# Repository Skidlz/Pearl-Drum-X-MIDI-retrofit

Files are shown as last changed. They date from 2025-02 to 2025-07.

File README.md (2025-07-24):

# Pearl Drum-X MIDI retrofit
 A MIDI retrofit board for Pearl's Drum-X (DRX-1) drum synthesizer

The project is designed around an Atmega*8 that controls a MAX528 octal DAC.

### Install Guide
[Here](https://docs.google.com/document/d/1SWIhVnxzadJWSYvPP88jSyq_Yxp76ufy1qYrGyIhOZM/edit?usp=sharing) is a quick explanation of the connections that need to be made to install the board.

### DAC
Five DAC outputs are used to generate triggers with different voltages based on MIDI velocity.

One output is used to generate eight control voltages for each of the five voices. Timing signals are received from the Pearl's motherboard, and are used to syncronize the stream of multiplexed CV signals.

### Use
The boards starts up in "MIDI learn" mode, and loads default settings for each voice. The board will assign itself to the first channel it receives a message on. The notes that it responds to, and the voice defaults are hard-coded in the firmware.

The voice paramaters are mapped to the first 40 MIDI CCs in this order: Pitch, Bend, Osc/Noise Mix, Over Tone, Attack, Filter, Decay, Level

### Atmega328p
The fuse bits of the Atmega328p need to be set for an external 16MHz crystal oscillator. The chips default to using the internal osc, and the firmware does not support this.
The following values can be programmed with avrdude: L:0xFF, H:0xD9, E:0xFF 

### Schematic
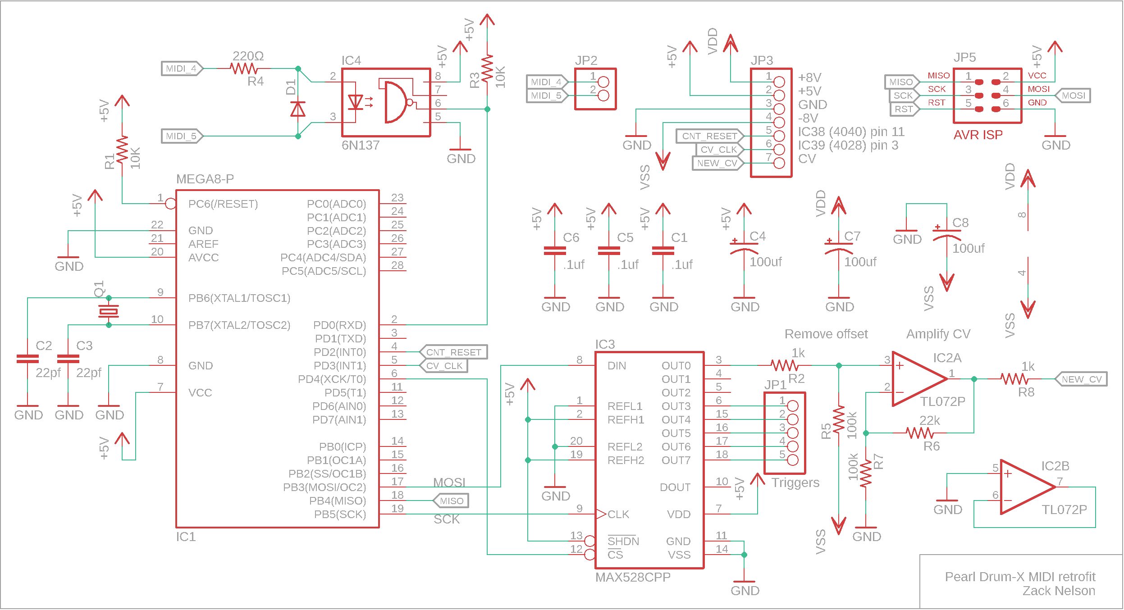
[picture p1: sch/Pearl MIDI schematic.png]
Schematic


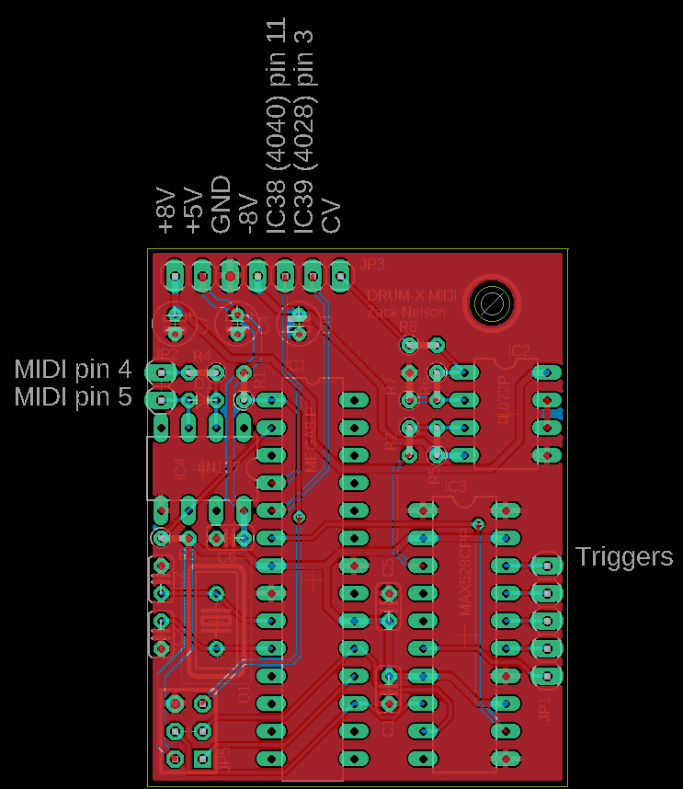
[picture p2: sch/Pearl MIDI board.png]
Board


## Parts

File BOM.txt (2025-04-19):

Qty Value         Device          Package      Parts      Description                          MF MPN       OC_FARNELL OC_NEWARK
1                 PINHD-1X2       1X02         JP2        PIN HEADER                                                            
1                 PINHD-1X5       1X05         JP1        PIN HEADER                                                            
1                 PINHD-1X7       1X07         JP3        PIN HEADER                                                            
3   .1uf          C-EU025-024X044 C025-024X044 C1, C5, C6 CAPACITOR, European symbol                                            
2   100k          R-US_0204/2V    0204V        R5, R7     RESISTOR, American symbol                                             
3   100uf         CPOL-USE1.8-4   E1,8-4       C4, C7, C8 POLARIZED CAPACITOR, American symbol                                  
2   10K           R-US_0204/2V    0204V        R1, R3     RESISTOR, American symbol                                             
1   16MHz         CRYSTALHC18U-V  HC18U-V      Q1         CRYSTAL                                           unknown    unknown  
1   1N4148        DIODE-D-2.5     D-2.5        D1         DIODE                                                                 
2   1k            R-US_0204/2V    0204V        R2, R8     RESISTOR, American symbol                                             
1   220Ω          R-US_0204/2V    0204V        R4         RESISTOR, American symbol                                             
1   22k           R-US_0204/2V    0204V        R6         RESISTOR, American symbol                                             
2   22pf          C-EU025-024X044 C025-024X044 C2, C3     CAPACITOR, European symbol                                            
1   6N137         6N137           DIL08        IC4        MOTOROLA OPTO COUPLER                   6N137     1328376    52M1895  
1   AVR-ISP-6VERT AVR-ISP-6VERT   AVR-ISP-6    JP5        AVR ISP-6 Serial Programming Header                                   
1   MAX528CPP     MAX528CPP       DIL20        IC3        DIGITAL/ANALOG CONVERTER                MAX528CPP 1379992    78C2818  
1   MEGA8-P       MEGA8-P         DIL28-3      IC1        MICROCONTROLLER                                   unknown    unknown  
1   TL072P        TL072P          DIL08        IC2        OP AMP

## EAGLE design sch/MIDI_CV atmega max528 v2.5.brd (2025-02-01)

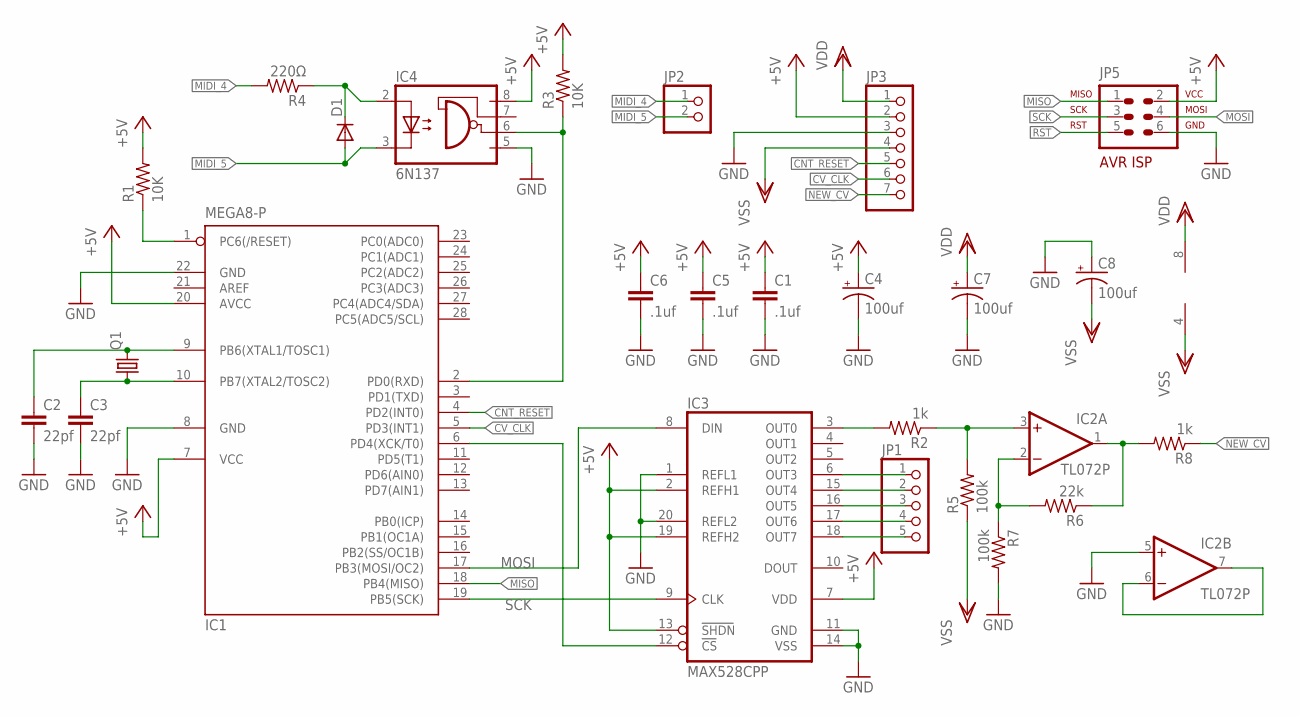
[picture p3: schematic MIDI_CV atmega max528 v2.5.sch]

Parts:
C1, C5, C6: .1uf; C025-024X044
C2, C3: 22pf; C025-024X044
C4, C7, C8: 100uf; E1,8-4
D1: DIODE-D-2.5; D-2.5
IC1: MEGA8-P; DIL28-3
IC2: TL072P; DIL08
IC3: MAX528CPP; DIL20
IC4: 6N137; DIL08
JP1: PINHD-1X5; 1X05
JP2: PINHD-1X2; 1X02
JP3: PINHD-1X7; 1X07
JP5: AVR-ISP-6VERT; AVR-ISP-6
Q1: CRYSTALHC18U-V; HC18U-V
R1, R3: 10K; 0204V
R2, R8: 1k; 0204V
R4: 220Ω; 0204V
R5, R7: 100k; 0204V
R6: 22k; 0204V

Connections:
+5V: C1.1, C4.+, C5.1, C6.1, IC1.7 (VCC), IC1.20 (AVCC), IC3.2 (REFH1), IC3.7 (VDD), IC3.13 (SHDN), IC3.19 (REFH2), IC4.8 (VCC), JP3.2, JP5.2, R1.2, R3.2
CNT_RESET: IC1.4 (PD2(INT0)), JP3.5
CV_CLK: IC1.5 (PD3(INT1)), JP3.6
GND: C1.2, C2.2, C3.2, C4.-, C5.2, C6.2, C7.-, C8.+, IC1.8 (GND), IC1.22 (GND), IC2.5 (+IN), IC3.1 (REFL1), IC3.11 (GND), IC3.14 (VSS), IC3.20 (REFL2), IC4.5 (GND), JP3.3, JP5.6, R7.2
MIDI_4: JP2.1, R4.2
MIDI_5: D1.A, IC4.3 (C), JP2.2
MISO: IC1.18 (PB4(MISO)), JP5.1
MOSI: IC1.17 (PB3(MOSI/OC2)), IC3.8 (DIN), JP5.4
unnamed: IC2.2 (-IN), R6.2, R7.1
unnamed: IC3.6 (OUT3), JP1.1
unnamed: IC3.15 (OUT4), JP1.2
unnamed: IC1.6 (PD4(XCK/T0)), IC3.12 (CS)
unnamed: IC3.16 (OUT5), JP1.3
unnamed: IC3.17 (OUT6), JP1.4
unnamed: D1.C, IC4.2 (A), R4.1
unnamed: IC3.18 (OUT7), JP1.5
unnamed: C2.1, IC1.9 (PB6(XTAL1/TOSC1)), Q1.2
unnamed: IC1.2 (PD0(RXD)), IC4.6 (VO), R3.1
unnamed: C3.1, IC1.10 (PB7(XTAL2/TOSC2)), Q1.1
unnamed: IC2.1 (OUT), R6.1, R8.2
unnamed: IC2.3 (+IN), R2.1, R5.2
unnamed: IC3.3 (OUT0), R2.2
unnamed: IC2.6 (-IN), IC2.7 (OUT)
NEW_CV: JP3.7, R8.1
RST: IC1.1 (PC6(/RESET)), JP5.5, R1.1
SCK: IC1.19 (PB5(SCK)), IC3.9 (CLK), JP5.3
VDD: C7.+, IC2.8 (V+), JP3.1
VSS: C8.-, IC2.4 (V-), JP3.4, R5.1

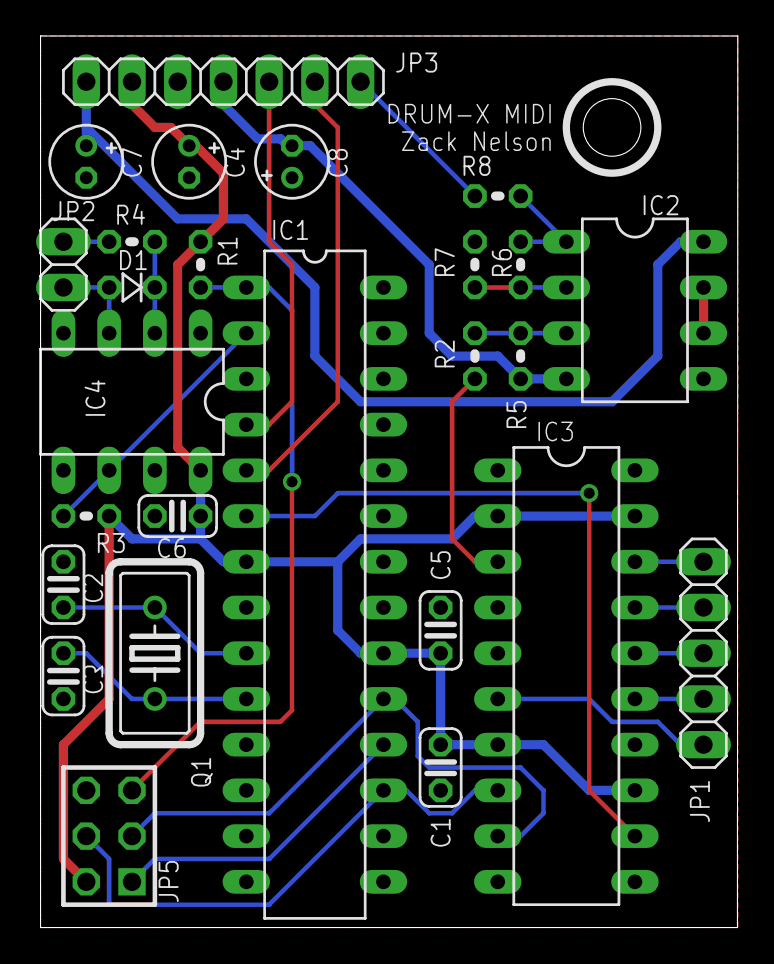
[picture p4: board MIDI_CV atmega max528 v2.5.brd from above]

Board: 2 copper layers, 38.7 x 49.5 mm, 26 parts (0 on the bottom side), 28 nets.

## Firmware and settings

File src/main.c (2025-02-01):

// Pearl CV - Zack Nelson
#include <stdint.h>
#include <avr/io.h>
#include <avr/interrupt.h>
#include <util/delay.h>
#include "uart.h"
#include "midi.h"
#include "MAX528.h"

#define F_CPU 16000000UL

//Values per voice
//Pitch, Bend, Osc/Noise Mix, Over Tone, Attack, Filter, Decay, Level
uint8_t cvs[5][8] = {
        { 128, 96,  128, 128, 128, 128, 64,  128 },
        { 128, 128, 128, 64,  64,  128, 64,  128 },
        { 196, 128, 255, 128, 64,  128, 128, 128 },
        { 128, 128, 255, 128, 64,  128, 128, 128 },
        { 64,  128, 255, 128, 64,  128, 128, 128 }};

#define trig_max 57 //number of 5.7KHz cycles before trig turns off
uint8_t trig_cnt[5] = { 0, 0, 0, 0, 0 }; //time trigger has been high
uint8_t trig_velo[5] = { 127, 127, 127, 127, 127 }; //amplitude of trigger

uint8_t mux_cnt = 0;

ISR (INT0_vect) {
    mux_cnt = 0;
}

ISR (INT1_vect) { //write CV
    uint8_t x = mux_cnt & 0b111;
    uint8_t y = (mux_cnt >> 3) & 0b111;
    if (mux_cnt++ >= 40) mux_cnt = 0; //error catch
    uint8_t cv = cvs[y][x]; //lookup CV
    max_wr_command(0b1, cv); //write CV to out0

    for (int voice = 0; voice < 5; voice++) {
        if (trig_cnt[voice]) { //if trig active
            if (trig_cnt[voice] == 1) { //turn trig on
                max_wr_command(0b1000 << voice, trig_velo[voice]); //write CV
            } else if (trig_cnt[voice] >= trig_max) { //trig turn off
                max_wr_command(0b1000 << voice, 0); //write CV
            }

            trig_cnt[voice]++;
        }
    }
}

void note_on(uint8_t note, uint8_t vel) {
    uint8_t voice = 0xff;
    switch (note) {
        case 48://35: //Bass
        case 49://36: //Kick
            voice = 0;
            break;
        case 50://38: //Snare
        case 51://40: //Electronic Snare
            voice = 1;
            break;
        case 52://43: //Floor tom
        case 53://45: //Low Tom
            voice = 2;
            break;
        case 54://47: //Low-Mid Tom
        case 55://48: //High-Mid Tom
            voice = 3;
            break;
        case 56://50: //High Tom
            voice = 4;
    }

    if (voice != 0xff) {
        trig_cnt[voice] = 1; //enable
        trig_velo[voice] = vel << 1; //set velocity
    }
}

void control_change(uint8_t param, uint8_t val) {
    //calculate position in voice value matrix
    uint8_t x = param & 0b111;
    uint8_t y = param >> 3;

    if (y >= 4) y = 4;
    cvs[y][x] = val << 1; //store value
}

int main() {
    uart_init(31250);

    set_cntrl_chng(control_change); //set function to handle control changes
    set_MIDI_key_press(note_on); //set function to handle note on
    //set_MIDI_key_release(); //set function to handle note off

    UCSR0B &= ~(1 << TXEN0); //Disable transmitter

    cli();// disable all interrupts

    //setup external interrupts
    EICRA |= (1 << ISC11) | (1 << ISC10) | (1 << ISC01) | (1 << ISC00); //rising edge
    //MCUCR |= (1 << ISC11) | (1 << ISC10) | (1 << ISC01) | (1 << ISC00); //rising edge
    EIMSK |= (1 << INT1) | (1 << INT0); //enable int
    //GIMSK |= (1 << INT1) | (1 << INT0);      // Turns on INT0

    DDRB = 0xff; //DAC SPI data bus
    //PB3 MOSI
    //PB4 MISO
    //PB5 SCK
    DDRC = 0b00111111; //switch outputs
    //PC1 CV Switch
    DDRD = 0b11110010; //0=input
    //PD0 = MIDI in
    //PD2 = INT0 = Count Reset
    //PD3 = INT1 = CV clock
    //PD4 = DAC CS
    PORTD = 0b1000; //pullup INT pin
    PORTB = 0;
    PORTC = 0; //switches off

    //-------------------------------
    max_init(); //configure DAC
    _delay_ms(1);

    sei();// enable all interrupts

    while (1) if (uart_test()) handle_midi();

    return 1;
}

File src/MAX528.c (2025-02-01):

//MAX528 DAC - Zack Nelson
#include <avr/io.h>
#include <util/delay.h>
#include "MAX528.h"

void max_init() {
    MAXDDR |= (1 << MAX_DAT) | (1 << MAX_CLK) | (1 << MAX_CS);
    DDRB = 0xff; //data out

    SPCR = (1 << SPE) | (1 << MSTR); //enable spi as master
    SPSR = (1 << SPI2X); //double speed clock
    max_wr_command(0x00, 0xff); //buffer all outs
}

void max_wr_byte(uint8_t out_byte) {
    SPDR = out_byte;
    while (!(SPSR & (1 << SPIF)));
}

void max_wr_command(uint8_t addr, uint8_t data) {
    MAXPORT &= ~(1 << MAX_CS); //enable cs
    SPDR = addr;
    while (!(SPSR & (1 << SPIF)));
    SPDR = data;
    while (!(SPSR & (1 << SPIF)));
    MAXPORT |= (1 << MAX_CS); //disable cs
}

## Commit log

2025-04-19 Adding BOM
2025-04-19 Update README.md
    Added fuse bits
